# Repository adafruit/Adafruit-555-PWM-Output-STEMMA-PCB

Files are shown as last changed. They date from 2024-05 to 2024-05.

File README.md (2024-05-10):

## Adafruit 555 PWM Output STEMMA - 1.4K to 25 KHz or 1.4 to 250 Hz - STEMMA JST PH 2mm PCB

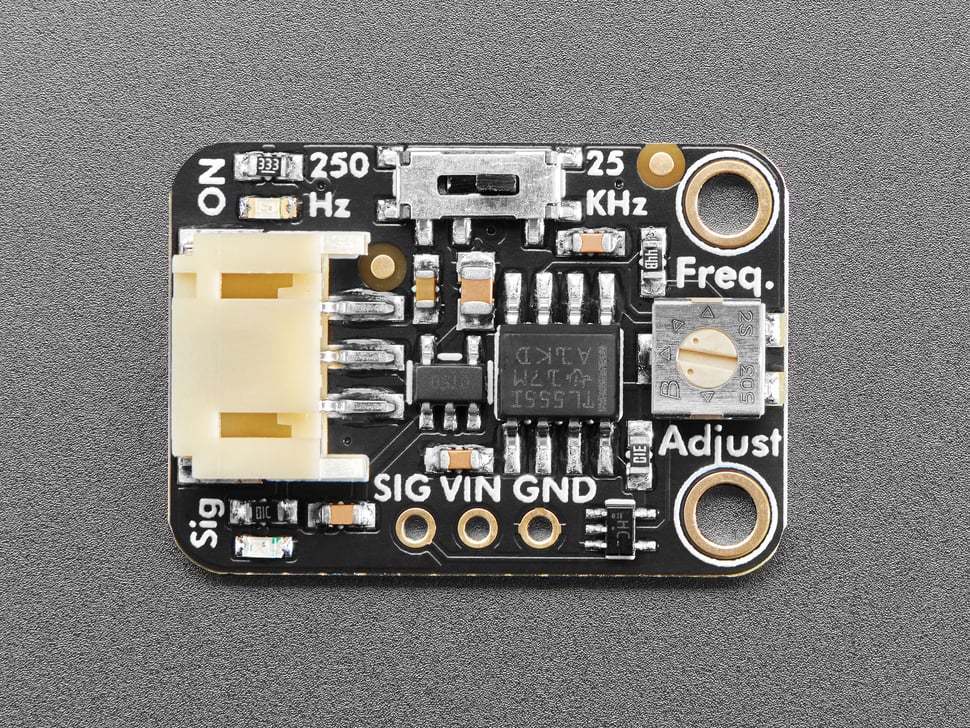
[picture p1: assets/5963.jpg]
<a href="http://www.adafruit.com/products/5963"><br/>
Click here to purchase one from the Adafruit shop</a>

PCB files for the Adafruit 555 PWM Output STEMMA - 1.4K~25 KHz or 1.4~250 Hz - STEMMA JST PH 2mm. 

Format is EagleCAD schematic and board layout
* https://www.adafruit.com/product/5963

### Description

How many times have we heard "hey you could have just replaced that microcontroller with a 555"? Maybe 555 times! But we always find wiring up a timer chip to be a bit of a pain, you need quite a few components - especially if you want a buffered output. That's why we designed the Adafruit 555 PWM Output STEMMA - a fully-assembled 555 timer board with adjustable PWM square-wave output.

We originally came up with this idea when someone requested we make a 'PC Fan Dummy' board, that can generate a 100Hz signal for faking a PC fan's tachometer signal to a motherboard. But then we thought that sometimes we want a square wave for driving a piezo, or as an audio input, or to modulate an IR signal. So we made it a little more general-purpose.

You can select between two 'ranges': approximately 1.4K~25 KHz or 1.4~250 Hz. The onboard trimmer pot will tune the actual output between those values. You can use a logic analyzer, oscilloscope, multimeter with frequency-counting, or even an audio input jack on a computer, to determine the precise value if you need more than a rough number. The output is a DC square wave, driven by a 74HC1G04
buffer so it can sink/source up to 12.5mA.

You can power the board from 3V to 12VDC, an onboard regulator will pin the input to the 555 and buffer to 5V max. That means that between 3V and 5V power, the signal peak will be at the same logic level as the power. Above 5V, the output will be pegged to 5V.

Each STEMMA board is a fully assembled and tested PCB but no cable. No soldering is required to use it, but you will need to pick up a 2mm pitch, 3-pin STEMMA JST PH cable. Alternatively, if you do want to solder, there's a 0.1" spaced header for power/ground/signal.

### License

Adafruit invests time and resources providing this open source design, please support Adafruit and open-source hardware by purchasing products from [Adafruit](https://www.adafruit.com)!

Designed by Limor Fried/Ladyada for Adafruit Industries.

Creative Commons Attribution/Share-Alike, all text above must be included in any redistribution. 
See license.txt for additional details.

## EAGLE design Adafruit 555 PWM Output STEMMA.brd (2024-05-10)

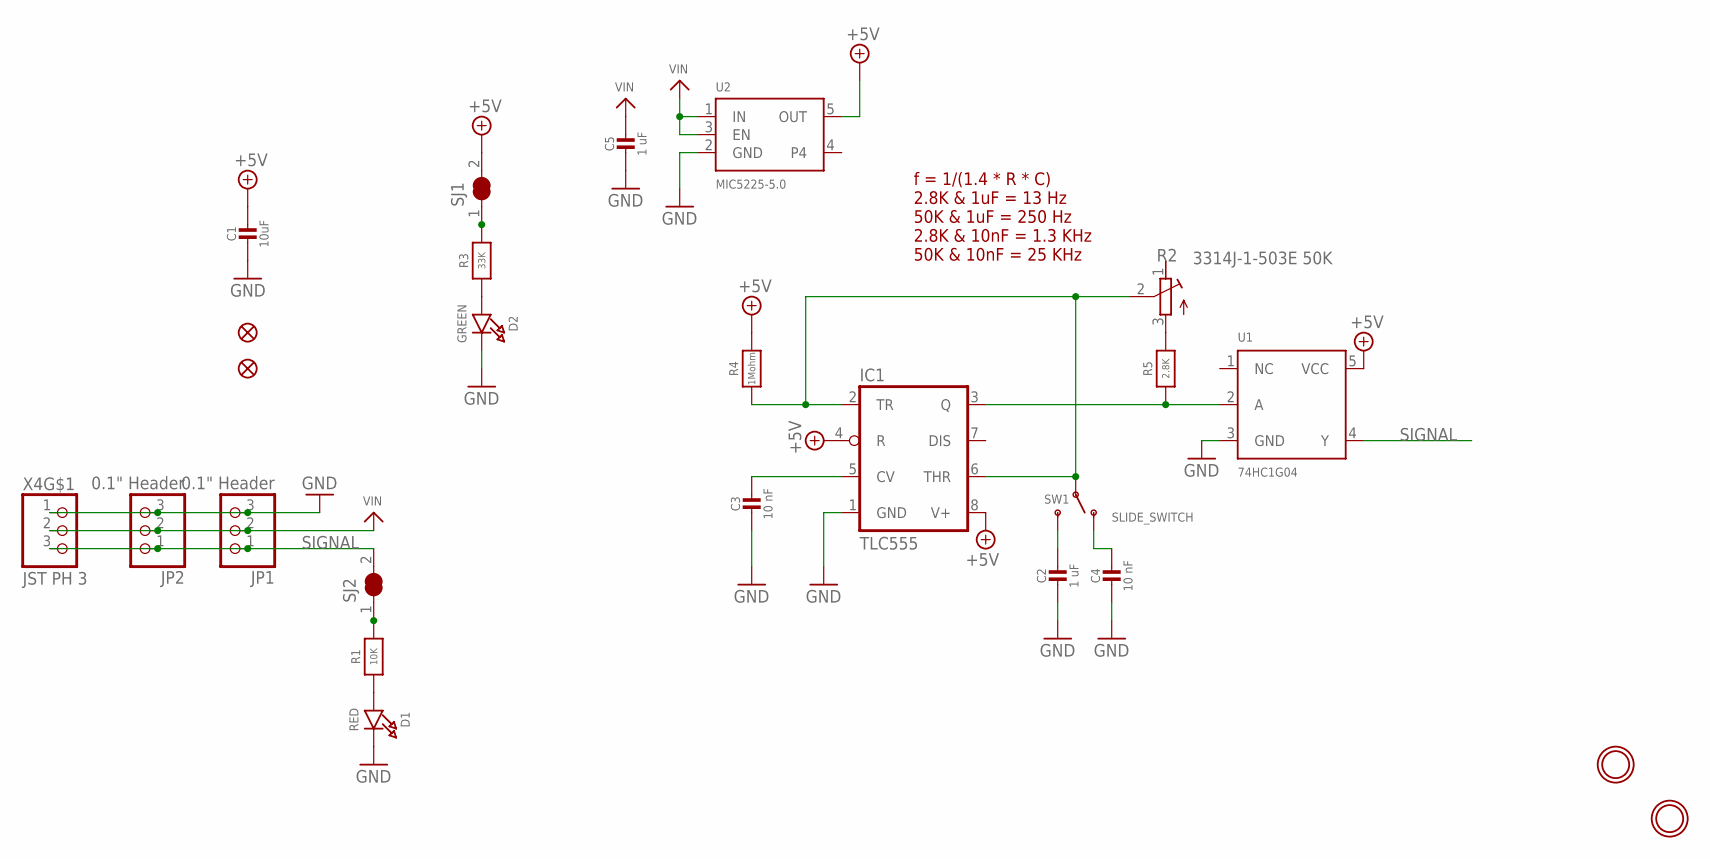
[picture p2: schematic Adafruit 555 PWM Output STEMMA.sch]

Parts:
C1: 10uF; 0805-NO
C2, C5: 1 uF; 0603-NO
C3, C4: 10 nF; 0603-NO
D1: RED; CHIPLED_0603_NOOUTLINE
D2: GREEN; CHIPLED_0603_NOOUTLINE
FID2, FID3: FIDUCIAL_1MM
IC1: TLC555; SO08
JP1: 0.1" Header; 1X03_OVAL
JP2: 0.1" Header; 1X03_ROUND
R1: 10K; 0603-NO
R2: 3314J-1-503E 50K; RTRIM3314J
R3: 33K; 0603-NO
R4: 1Mohm; 0603-NO
R5: 2.8K; 0603-NO
SJ1, SJ2: SOLDERJUMPER_CLOSED; SOLDERJUMPER_CLOSEDWIRE
SW1: SLIDE_SWITCH; SPDT_SMT_SSSS811101
U1: 74HC1G04; SC70-5
U2: MIC5225-5.0; SOT23-5
U$1, U$8: MOUNTINGHOLE2.5; MOUNTINGHOLE_2.5_PLATED
X4: JST PH 3; JSTPH3

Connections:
+5V: C1.1, IC1.4 (R), IC1.8 (V+), R4.2, SJ1.2, U1.5 (VCC), U2.5 (OUT)
GND: C1.2, C2.2, C3.2, C4.2, C5.2, D1.C, D2.C, IC1.1 (GND), JP1.3, JP2.3, U1.3 (GND), U2.2 (GND), X4.1
unnamed: R3.2, SJ1.1
unnamed: D1.A, R1.1
unnamed: R1.2, SJ2.1
unnamed: C2.1, SW1.C (S)
unnamed: IC1.2 (TR), IC1.6 (THR), R2.2 (S), R4.1, SW1.B
unnamed: C3.1, IC1.5 (CV)
unnamed: C4.1, SW1.A (O)
unnamed: R2.3 (A), R5.2
unnamed: IC1.3 (Q), R5.1, U1.2 (A)
unnamed: D2.A, R3.1
SIGNAL: JP1.1, JP2.1, SJ2.2, U1.4 (Y), X4.3
VIN: C5.1, JP1.2, JP2.2, U2.1 (IN), U2.3 (EN), X4.2

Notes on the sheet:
f = 1/(1.4 * R * C) 2.8K & 1uF = 13 Hz 50K & 1uF = 250 Hz 2.8K & 10nF = 1.3 KHz 50K & 10nF = 25 KHz

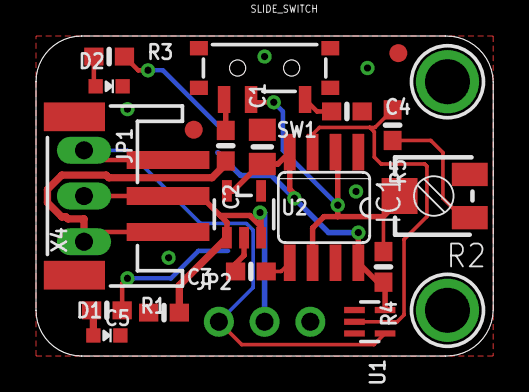
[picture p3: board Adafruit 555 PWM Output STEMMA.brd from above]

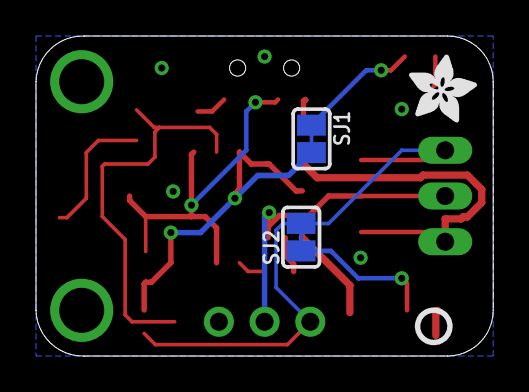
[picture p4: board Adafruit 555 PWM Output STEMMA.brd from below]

Board: 2 copper layers, 25.4 x 17.8 mm, 43 parts (11 on the bottom side), 14 nets.

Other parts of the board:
PLABEL0: PLABEL0
PLABEL1: PLABEL1
PLABEL7: PLABEL7
PLABEL8: PLABEL8
PLABEL9: PLABEL9
PLABEL13: PLABEL13
PLABEL14: PLABEL14
PLABEL15: PLABEL15
PLABEL19: PLABEL19
PLABEL20: PLABEL20
PLABEL21: PLABEL21
PLABEL22: PLABEL22
PLABEL23: PLABEL23
PLABEL24: PLABEL24
PLABEL25: PLABEL25
PLABEL26: PLABEL26
U$5: PCBFEAT-REV-040
U$15: ADAFRUIT_3.5MM

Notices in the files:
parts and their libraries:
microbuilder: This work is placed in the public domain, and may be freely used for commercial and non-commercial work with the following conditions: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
